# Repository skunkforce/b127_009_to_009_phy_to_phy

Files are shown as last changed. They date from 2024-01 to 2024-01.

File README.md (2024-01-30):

# edgy_board number b127
Use this if you want to connect two phys together without cable, magnetics or connectors. 
[view in borwser with kiCnvas](https://kicanvas.org/?github=https://github.com/skunkforce/b127_009_to_009_phy_to_phy/tree/master/board)

This design is part of the [edgy board project](https://github.com/skunkforce/edgy_boards).

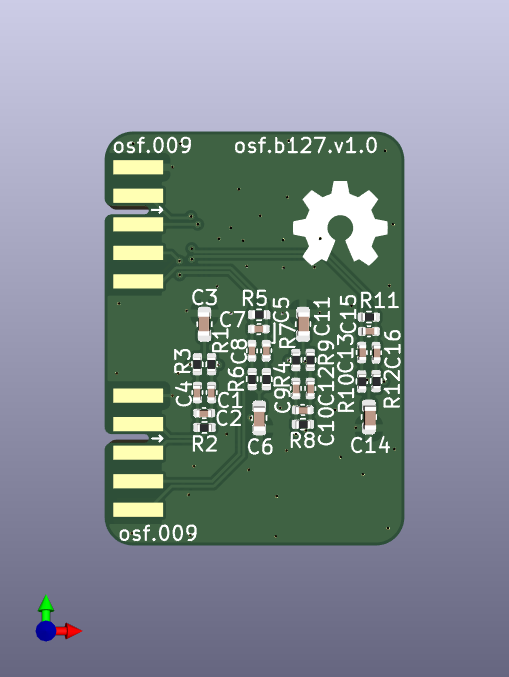
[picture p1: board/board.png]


# getting started
This repository uses submodules. After cloning use the command 

```$ git submodule update --init --recursive```

to pull the submodules before opening the project with kicad. 

# Tests
Tests can be found in [TESTS.md](TESTS.md)

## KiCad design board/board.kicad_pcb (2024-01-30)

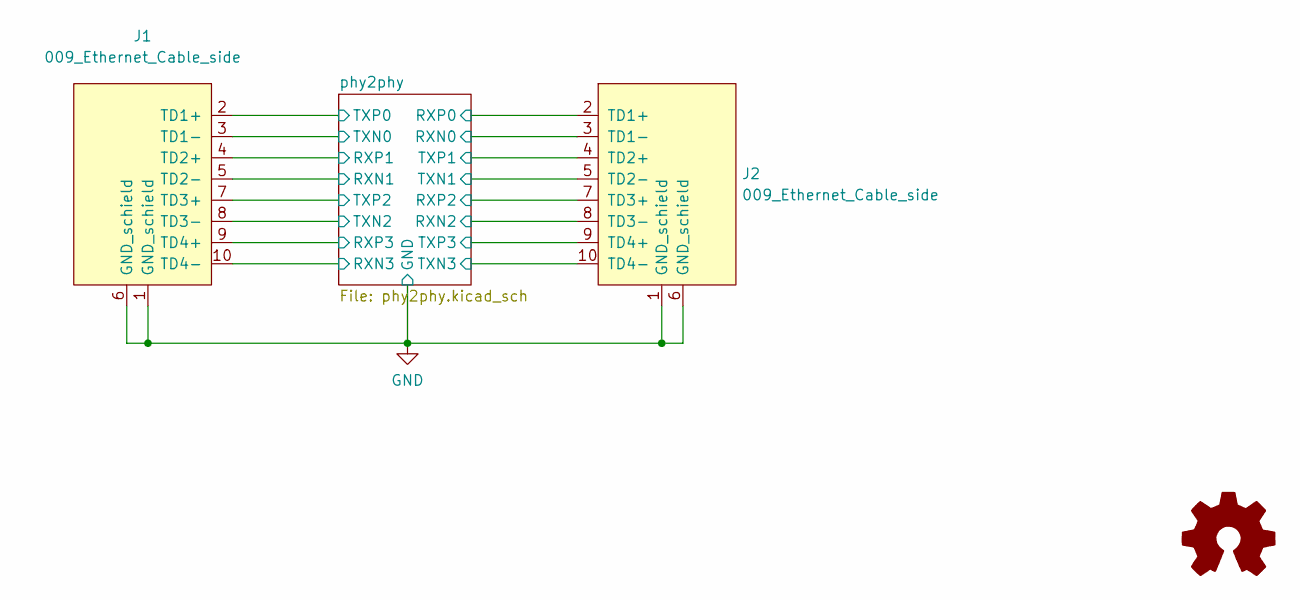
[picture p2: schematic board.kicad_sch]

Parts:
J1, J2: 009_Ethernet_Cable_side; on_edge_2x05_device
LOGO1: Logo_Open_Hardware_Small; OSHW-Symbol_6.7x6mm_SilkScreen

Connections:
/phy2phy/RXN0: J2.3 (TD1-); also elsewhere on the board
/phy2phy/RXN1: J1.5 (TD2-); also elsewhere on the board
/phy2phy/RXN2: J2.8 (TD3-); also elsewhere on the board
/phy2phy/RXN3: J1.10 (TD4-); also elsewhere on the board
/phy2phy/RXP0: J2.2 (TD1+); also elsewhere on the board
/phy2phy/RXP1: J1.4 (TD2+); also elsewhere on the board
/phy2phy/RXP2: J2.7 (TD3+); also elsewhere on the board
/phy2phy/RXP3: J1.9 (TD4+); also elsewhere on the board
/phy2phy/TXN0: J1.3 (TD1-); also elsewhere on the board
/phy2phy/TXN1: J2.5 (TD2-); also elsewhere on the board
/phy2phy/TXN2: J1.8 (TD3-); also elsewhere on the board
/phy2phy/TXN3: J2.10 (TD4-); also elsewhere on the board
/phy2phy/TXP0: J1.2 (TD1+); also elsewhere on the board
/phy2phy/TXP1: J2.4 (TD2+); also elsewhere on the board
/phy2phy/TXP2: J1.7 (TD3+); also elsewhere on the board
/phy2phy/TXP3: J2.9 (TD4+); also elsewhere on the board
GND: J1.1 (GND_schield), J1.6 (GND_schield), J2.1 (GND_schield), J2.6 (GND_schield); also elsewhere on the board

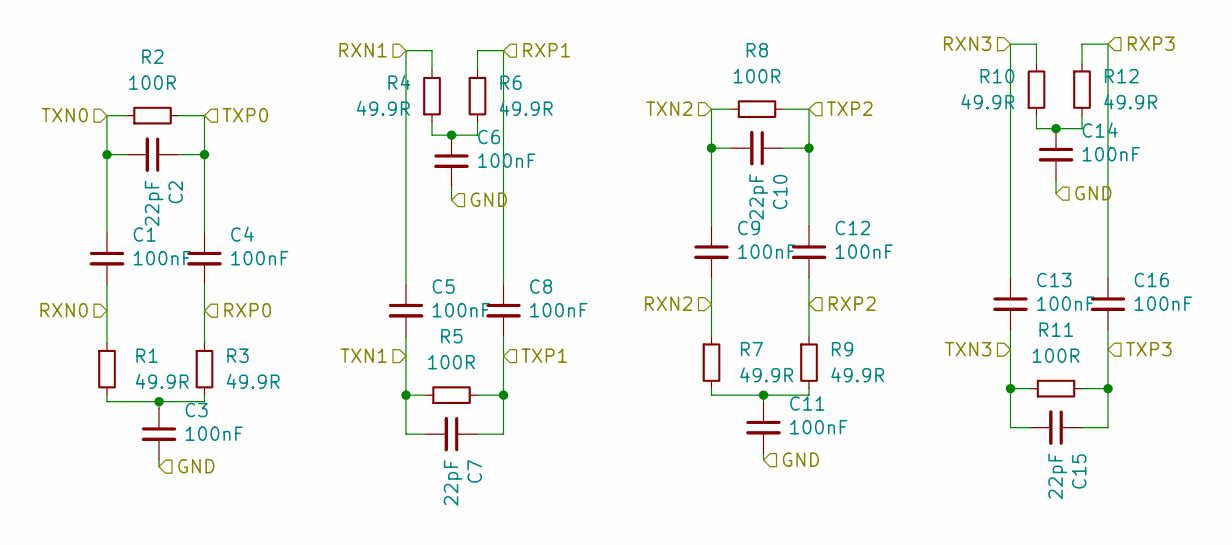
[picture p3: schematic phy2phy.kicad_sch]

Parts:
C1, C3, C4, C5, C6, C8, C9, C11, C12, C13, C14, C16: 100nF; C_0402_1005Metric; lcsc C307331
C2, C7, C10, C15: 22pF; C_0402_1005Metric; lcsc C1555
R1, R3, R4, R6, R7, R9, R10, R12: 49.9R; R_0402_1005Metric; lcsc C25120
R2, R5, R8, R11: 100R; R_0402_1005Metric; lcsc C25076

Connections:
/phy2phy/RXN0: C1.2, R1.1; also elsewhere on the board
/phy2phy/RXN1: C5.1, R4.2; also elsewhere on the board
/phy2phy/RXN2: C9.2, R7.1; also elsewhere on the board
/phy2phy/RXN3: C13.1, R10.2; also elsewhere on the board
/phy2phy/RXP0: C4.2, R3.1; also elsewhere on the board
/phy2phy/RXP1: C8.1, R6.1; also elsewhere on the board
/phy2phy/RXP2: C12.2, R9.1; also elsewhere on the board
/phy2phy/RXP3: C16.1, R12.1; also elsewhere on the board
/phy2phy/TXN0: C1.1, C2.2, R2.1; also elsewhere on the board
/phy2phy/TXN1: C5.2, C7.2, R5.1; also elsewhere on the board
/phy2phy/TXN2: C9.1, C10.2, R8.1; also elsewhere on the board
/phy2phy/TXN3: C13.2, C15.2, R11.1; also elsewhere on the board
/phy2phy/TXP0: C2.1, C4.1, R2.2; also elsewhere on the board
/phy2phy/TXP1: C7.1, C8.2, R5.2; also elsewhere on the board
/phy2phy/TXP2: C10.1, C12.1, R8.2; also elsewhere on the board
/phy2phy/TXP3: C15.1, C16.2, R11.2; also elsewhere on the board
GND: C3.2, C6.2, C11.2, C14.2; also elsewhere on the board
unnamed: C3.1, R1.2, R3.2
unnamed: C6.1, R4.1, R6.2
unnamed: C11.1, R7.2, R9.2
unnamed: C14.1, R10.1, R12.2

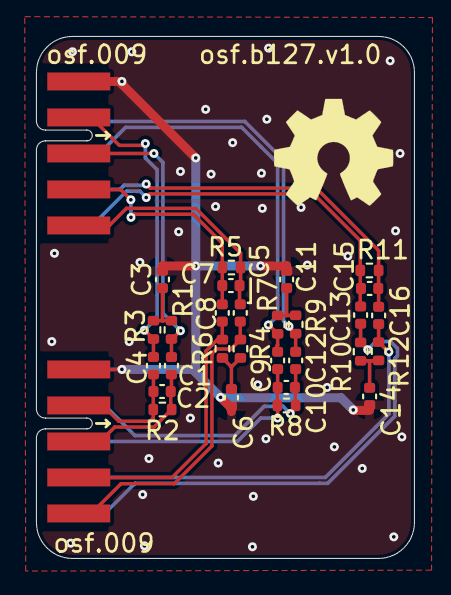
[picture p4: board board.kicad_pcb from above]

Board: 2 copper layers, 21.0 x 29.0 mm, 31 parts (0 on the bottom side), 21 nets.

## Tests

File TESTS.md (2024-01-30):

# communication test
## setup
Connected internet --> b135 (magjack) --> b119 (switch) --> b127 --> b049 (Raspberry Pi CM4 breakout)
## results
The pi was able to communicate with the internet.
